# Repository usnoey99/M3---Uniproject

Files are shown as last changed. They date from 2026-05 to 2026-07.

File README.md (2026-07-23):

# M3 - Gruppe 8 RACE TRACK

### Video Demonstration

[RaceTrack Demo Video](https://github.com/user-attachments/assets/90ffaf7d-e557-4ccf-97b7-1830bb99d353)

---

## Manuals & Documentation

Check out the detailed guides and manuals for more information:

* 📖 [User Manual (PDF)](./docs/RacetrackKurzanleitung.pdf)
* 📄 [Developer & Setup Guide](./docs/M3%20-%20Gruppe%208%20-%20Manuell.pdf)

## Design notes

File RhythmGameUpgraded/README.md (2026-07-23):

# 2. Abgabe: PyBadge Rhythm Game

**Abgabe bis: 12. Mai**

## 1) Anpassung des Rhythm Games

- **Aufgabe:** Das Rhythm Game so anpassen, dass nach der Schwierigkeitsauswahl:
  - der Bildschirm schwarz wird, bevor das eigentliche Spiel startet
  - die **Neopixel-LEDs** anstelle des Displays verwendet werden, um Spielsignale anzuzeigen  
    - Falls die Neopixel nicht funktionieren, kann alternativ die **D13-LED** genutzt werden
- **Abgabe:**  
  - `.ino` Datei
  - kurzes Demo-Video (`.mp4`)

**Hinweis:**  
Die LEDs zeigen die aktuelle Spielaufgabe an (z.B. grün für einfache Beats, rot für schwierige Beats).

---

## 2) Storyboards

- **Anforderung:** Mindestens 3 verschiedene Spielideen
- **Fokus:**
  - Nutzerinteraktion
  - Sensoren / Aktuatoren / zusätzliche Hardware
  - Feedback des Systems
- **Abgabe:** PDF-Datei mit den Storyboards

---

## 3) Zwischenpräsentation

- **Aufgabe:** Eine Spielidee auswählen und kurz vorstellen
- **Schwerpunkt:** Interaktion des Spiels
- **Dauer:** Max. 4 Minuten
- **Abgabe:** Präsentationsfolien als PDF

---

## 4) Endabgabe

Alle Materialien müssen am Ende in einer **ZIP-Datei** eingereicht werden:

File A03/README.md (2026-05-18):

# Woche 3

## Übersicht

In der dritten Woche arbeitet die Gruppe selbstständig am Projekt weiter.  
Der Fokus liegt auf:

- praktischer Arbeit im FabLab
- Planung benötigter Bauteile
- Dokumentation des Projektfortschritts

---

# Aufgaben

## 1. Werkstattaufgabe (FabLab)

Erstellt zwei kleinere Objekte, die mit eurem Projekt zusammenhängen.

### Anforderungen

- [x ] Ein Objekt mit dem **3D-Drucker** herstellen

- [x] Ein Objekt mit dem **Laser Cutter** herstellen
- [x] Eigene Designs verwenden (gemacht über pdf und freeCAD)
- [x] Keine fertigen Vorlagen aus dem Internet nutzen

### Ziel

Den gesamten Entwicklungs- und Herstellungsprozess selbst kennenlernen.

### Abgabe

- [x ] Fotos der beiden Objekte
- [x ] Kurze Erklärung zu den Objekten
- [ ] Objekte nächste Woche mitbringen

---

## 2. Bestellliste für Teile

Erstellt eine Liste aller benötigten Bauteile für das Projekt.

### Aufgaben

- [ ] Benötigte Komponenten sammeln
1. **Magnete**(100 Stück, 20x5) 3mmx2mm link: https://www.magnet-shop.net/neodym-magnete/scheibenmagnete/scheibenmagnet-3.0-x-2.0-mm-n35-nickel-haelt-300-g
2. **Neopixel** (noch nicht)
3. **Pogopins/connectors** (50x Stück) müssen 5 pins haben und auch direkt einen connector dazu oder einfach stiftleiste und buchsenleiste??
4. **Microcontroller** (20x stück) evtl noch zubehör wie platinen
5. **Potentiometer** 10k
- [ ] Mengen festlegen
- [ ] Fehlende Teile identifizieren

> Weitere Details folgen in einer separaten Ankündigung.

---

## 3. Fortschrittsbericht

Jede Gruppe erstellt einen kurzen Wochenbericht.

### Der Bericht soll folgende Fragen beantworten

- [ ] Welches Gruppenmitglied hat an welchen Aufgaben gearbeitet?
- [ ] Welchen Fortschritt habt ihr erzielt?
- [ ] Welche Probleme oder Herausforderungen gibt es aktuell?
- [ ] Was sind die nächsten Schritte für die kommende Woche?

### Format

- Maximal 2 DIN-A4-Seiten
- Schriftgröße: 12 pt
- Stichpunkte erlaubt
- Bilder optional
- Bilder zählen nicht zum Seitenlimit

---

# Abgabeformat

## Anforderungen

- [ ] Eine gemeinsame PDF-Datei pro Gruppe
- [ ] Namen aller Gruppenmitglieder
- [ ] Fortschrittsbericht
- [ ] Optional: Bilder des Projektfortschritts
- [ ] Bilder der erstellten Objekte mit kurzer Erklärung

---

# Bewertung

- Aktive Mitarbeit und Anwesenheit im Lab sind wichtig.
- Für diese Abgabe gibt es keine direkten Punkte.
- Der Arbeitsaufwand fließt in die Bewertung des finalen Projekts ein.
- Jedes Gruppenmitglied sollte am Ende alle Teilbereiche erklären können.

---

# Wichtiger Hinweis

Verspätete Abgaben werden negativ bewertet und können im schlimmsten Fall zum Ausschluss aus dem Praktikum führen.

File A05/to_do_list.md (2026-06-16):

# RACETRACK – To-Do Liste A05 | Yeonsu
- [x] **1. PyBadge Racing-Simulator (Prototyp)**
  - [x] Pseudo-3D Rennstrecke mit Basis-Formen (Himmel, Gras, Straße, Auto) implementiert
  - [x] Dynamische Scrolling-Animation der Fahrbahnmarkierungen (BPM fungiert als temporäres Gaspedal)
  - [x] UI-Anzeige für "GEAR" (Oktave) als statischer Platzhalter vorbereitet
  - [x] Temporäre Tastensteuerung (Button A/B für BPM) für die Prototyp-Phase ohne Hardware-Pedal eingerichtet

Der grafische PyBadge-Prototyp ist fertiggestellt: Die einfache Text-UI wurde durch eine Pseudo-3D-Rennstrecke mit flüssiger Scrolling-Animation ersetzt. Da das Hardware-Pedal noch fehlt, steuern die Buttons A/B temporär die BPM (Animationsgeschwindigkeit). Die "GEAR"-Anzeige (Oktave) dient vorerst als statischer Platzhalter, während die UART-Kommunikation fehlerfrei parallel zum neuen Rendering läuft.

- [x] **2. Grafik-Assets (Pixel Art) erstellen**
  - [x] Zeichen-Tool auswählen (z.B. Piskel (piskelapp.com) oder Pixilart (pixilart.com))
  - [x] Sprites entwerfen (Auto, Hintergrund, UI-Elemente)
  - [x] Assets formatgerecht exportieren (max. 160x128 Pixel, .bmp Format / 256 Farben)

- [x] **3. PyBadge Grafik-Integration (CircuitPython)**
  - [x] BMP-Dateien in den CIRCUITPY-Speicher übertragen
  - [x] adafruit_imageload Bibliothek einbinden
  - [x] Bisherige Platzhalter-Formen (TileGrids) durch echte Pixel-Art-Sprites ersetzen

Zudem wurden die bisherigen grafischen Platzhalter durch finale Pixel-Art-Assets (Retro-Hintergrund und Auto) ersetzt. Die erstellten 24-Bit-BMP-Dateien wurden mithilfe der adafruit_imageload-Bibliothek erfolgreich in den CircuitPython-Code eingebunden.

- [x] **4. ESP32 Audio-Synthesizer (Prototyp)**
  - [x] BluetoothA2DPSource Bibliothek integrieren
  - [x] Echtzeit-Klangsynthese (Sinuswelle) im ESP32 programmieren
  - [x] Notenfrequenzen (Circle of Fifths) mit der Audio-Ausgabe verknüpfen
  - [x] Bluetooth-Streaming an externen Lautsprecher einrichten

- [x] **5.BPM & Playback Synchronisation**
  - [x] Notenlänge dynamisch an die aktuelle BPM anpassen (80% des Beat-Intervalls)
  - [x] Audio-Trigger fehlerfrei in die bestehende millis()-Playback-Loop integrieren

Ein Echtzeit-Audiosynthesizer (Sinuswelle) wurde auf dem ESP32 implementiert, der die Frequenzen des Quintenzirkels berechnet und kabellos via Bluetooth A2DP streamt. Tonlänge und Timing passen sich dabei dynamisch der aktuellen BPM an. Damit ist das System nun visuell (PyBadge) und akustisch vollständig synchronisiert. Ein Praxistest mit einem echten Bluetooth-Lautsprecher steht aktuell noch aus und muss zeitnah durchgeführt werden.

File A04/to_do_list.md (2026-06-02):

# RACETRACK – To-Do Liste | Yeonsu

- [x] **1. Entwicklungsumgebung**
  - [x] ESP32 konfigurieren & Blink-Test erfolgreich

- [x] **2. UART-Kommunikation**
  - [x] ESP32 <-> PyBadge verbinden
  - [x] UART testen
  - [x] Befehle senden/empfangen (BPM_UP / BPM_DOWN / START / STOP)

- [x] **3. PyBadge (UI)**
  - [x] UART-Empfang implementieren
  - [x] Buttons -> UART-Befehle senden
  - [x] Display für NOTE / BPM / STATUS
  - [x] Nur UI-Logik (keine Berechnung)

- [x] **4. ESP32 Datenstruktur**
  - [x] BlockType (LEFT / RIGHT / STRAIGHT)
  - [x] Track-Array + playhead

- [x] **5. Eingabesystem (ESP32)**
  - [x] Serielle Eingabe (L / R / S / X)
  - [x] Track-Erstellung testen

Ich habe das technische Fundament erfolgreich fertiggestellt und die UART-Verbindung zwischen ESP32 und PyBadge stabil eingerichtet. Auf dem PyBadge läuft die komplette UI-Logik (CircuitPython) zur Anzeige von BPM, Note und Status sowie zum Senden von Button-Befehlen. Auf dem ESP32 wurde die Track-Datenstruktur implementiert und auf 18 Blöcke optimiert. Das Eingabesystem über den PC-Serienmonitor liest Streckenbefehle (L/R/S/X) fehlerfrei in das Array ein.

---

- [x] **6. Musik-Engine (ESP32)**
  - [x] Circle of Fifths implementieren
  - [x] Notenberechnung basierend auf Track-Richtung

- [x] **7. Playback-Engine (ESP32)**
  - [x] Playhead-Loop implementieren
  - [x] BPM-System im ESP32
  - [x] Timing mit millis()

- [x] **8. Integrationstest**
  - [x] UART-Kommunikation testen (ESP32 <-> PyBadge)
  - [x] BPM beeinflusst Playback
  - [x] Track -> Note -> Loop funktioniert
  - [x] Display zeigt Live-Daten korrekt

Ich habe die Musik- und Playback-Engine des ESP32 erfolgreich implementiert. Die Notenberechnung (Quintenzirkel) passt sich dynamisch der Strecke an, inklusive sicherem Loop-Reset auf die Startnote. Das Playback-Timing wird nun flüssig über millis() gesteuert und durch BPM-Limits (60-240) abgesichert. Der Integrationstest bestätigt eine fehlerfreie Umwandlung der Tracks in Musik sowie eine optimierte Echtzeit-Anzeige auf dem PyBadge (150ms Update-Rate).

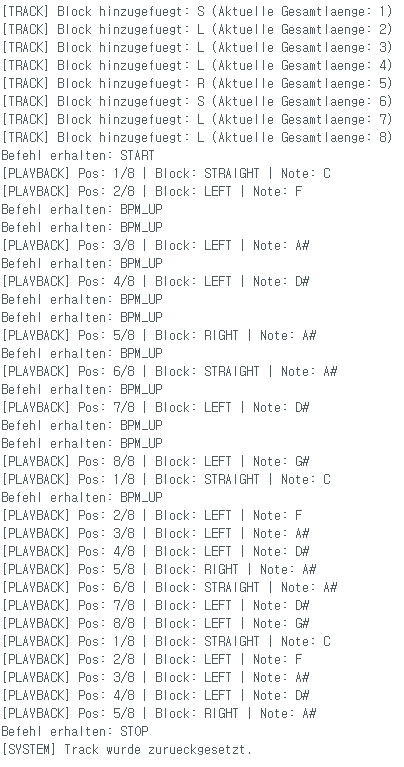
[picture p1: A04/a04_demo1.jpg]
UART Serial Monitor


- [ ] **Optional (Future)**
  - [ ] Pedal-Eingang für BPM (ESP32 übernimmt Steuerung)
  - [ ] Buzzer/Audio-Ausgabe

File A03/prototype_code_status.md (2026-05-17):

# RACETRACK – Prototype

## Beschreibung
Ein einfacher Musik-Step-Sequencer für den Adafruit PyBadge.

## Funktionen
- Circle-of-Fifths Musiksystem (F, C, G, D, A, E, B)
- Schrittbasierte Sequenz (Track-System)
- BPM-Steuerung mit Buttons (A = langsamer, B = schneller)
- Display zeigt Note, BPM und Track-Status
- WAV-Audio wird pro Note abgespielt
- START-Button startet den Sequencer
- SELECT-Button pausiert den Sequencer

## Status
- Sequencer funktioniert
- Display funktioniert
- BPM-Steuerung funktioniert
- WAV-Wiedergabe funktioniert jetzt
- Start/Stop-Steuerung funktioniert

## Aktuelle Einschränkungen
- PyBadge unterstützt nur einen Audio-Stream gleichzeitig
- Keine echte gleichzeitige Wiedergabe mehrerer WAV-Dateien
- Echtzeit-Audio-Mixing ist aktuell nicht möglich

## Nächste Schritte
- Mehrspur-Audio / Audio-Engine untersuchen
- BPM-abhängige Audio-Geschwindigkeit testen
- Hardware-Input mit Microswitches und Pedalen erweitern

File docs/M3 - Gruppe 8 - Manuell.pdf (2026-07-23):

## M3 - Gruppe 8 - A10 Racetrack

Finja Rang
Yeonsu Kang
Merle Hoffmann
1. Idee
Die Grundidee war, angelegt an eine Rennstrecke, ein modulares Spiel zu entwickeln, mit dem man sich einen eigenen Song bauen kann. Je nach Bauteil (Linkskurve, Rechtskurve und Gerade) verändert sich der Ton einen Schritt nach Links oder Rechts im Quintenzirkel. Dadurch entsteht eine kurze Melodie, die immer wieder geloopt wird. Dabei wollen wir erreichen, dass man spielerisch eine einfache Melodie mit Kicks und Snares erstellen kann und dabei gleichzeitig eine haptische Darstellung von Tönen erlebt.
Die physikalischen Streckenblöcke haben dabei jeweils einen ATTiny und bilden eine Chain die vom ESP32 ausgelesen wird. Da jedes Streckenteil einen ATTiny mit einzigartiger Erkennungs-ID besitzt, können wir auch ein Kick- und Snare-Pattern pro Modul durch Widerstände und Jumper codieren. Diese kann man während des Loops auch immer umstecken, da wir durch eine I2C-Verbindung mit dem ESP32 diese immer neu ablesen. Somit entsteht zusätzlich ein weiteres Element in der Musik, welches eher an einen Synthesizer anlehnt. Zusätzlich haben wir noch ein 3D-gedrucktes Pedal mit einem Potentiometer, mit dem man durch Drücken dynamisch den BPM der Musik schneller werden lassen kann.
Auch haben unsere Streckenteile jeweils zwei eingebaute Neopixel, sodass man durch Leuchten in den Farben Rot und Grün erkennen kann, wo man sich im Loop und im Abspielen der Töne gerade befindet (das aktuelle Teil leuchtet Grün, während alle anderen Teile rot leuchten).
Der PyBadge dient hauptsächlich als reine UI. Dabei gibt es das Start- und Stopp-Menü sowie einen Warnbildschirm, falls die Strecke nicht erkannt wird. Zusätzlich kann man auch die Startnote am Anfang über die hoch und runter Knöpfe auswählen. Während der Track läuft, gibt der PyBadge eine visuelle Darstellung eines fahrenden Autos aus mit dem aktuell abspielenden Ton, um die Tonerkennung zu vereinfachen.
2. Benötigte Komponenten
- PyBadge
■ GRD Kabel
■ RX Kabel
■ TX Kabel
■ Batterie oder Stromanschluss ■ 3d-Gehäuse

- ESP32
- Arduino UNO zum Attiny flashen
- 6x Jumperkabel zum ATtiny flashen
- Laptop o.Ä. mit USB Anschluss
- Bluetooth-Lautsprecher
- Potentiometer 25k
- 3.3V Netzgerät
- 2,54 mm Stiftleisten
■ diese haben wir in 100x 2er Pins getrennt und dann oben mit Lötzinn verbunden (als homemade Jumper)
■ dann wurden sie mit Heißkleber in die 3D-gedruckten Pylonen geklebt
Wir haben 13 Streckenteile (3 Links- 3 Rechtskurven und 7 Geraden), die alle die gleichen Komponenten haben. Also ist hier ein Beispiel eines Streckenteils und dieses dann 13 mal:
- 8-Bit-ATtiny 85
- Lochrasterplatine(-n) (Gerade: ca. 10 x 4 cm, Kurven: 2x ca. 5 x 4 cm)
- IC-Sockel
- JST - Buchsengehäuse, 1x6-polig - XH
- JST - Stiftleiste, gerade, 1x6-polig - XH
- 6x JST - Crimpkontakt, Buchse - XH
- 1x 100 µF Elektrolyt-Kondensator
- 2x 10k Widerstände
- 2x 1k Widerstände
- 2x 2k Widerstände (2x1k Widerstände)
- 2x 4k Widerstände (1x 1,8k und 1x 2,2k Widerstände)
- 2x 8k Widerstände (1x 6,8k und 1x 1,2k Widerstände)
- 8x 2,0 x 3,0 mm Scheibenmagnete
- 8x 2er Buchsen
■ + weitere 8x 2er Buchsen
■ diese wurden aufeinander gesteckt und mit Schrumpfschläuchen verbunden damit sie lang genug sind um oben aus dem Gehäuse herausragen zu können
- Schrumpfschläuche
- Gnd Kabel (mehrere Stücke)
- Vcc Kabel (mehrere Stücke)
- 2x Neopixel
- Kabel für SDA (mehrere Stücke)
- Kabel für SCL (mehrere Stücke)
- Kabel für Neo-Data (mehrere Stücke)
- Kabel für Chain-Data (mehrere Stücke)
- Sekundenkleber
- Heißkleber
- 3D-Druck Gehäuse

3. Verkabelung
- UART2 zwischen ESP32 und PyBadge
■ GPIO16=RXD2
■ GPIO17=TXD2
- I2C-Bus (Master ESP32) zu dem ersten angesteckten ATTiny (Adressbereich 0x10–0x1F) durch Stecker
■ GPIO21=SDA
■ GPIO22=SCL
- Chain-Signal zwischen ESP32 und dem ersten angesteckten ATTiny ■ GPIO4=PB4 (Chain-In)
- NeoPixel-Datachain zwischen ESP32 und dem ersten angesteckten ATTiny
■ GPIO5=Neopixel Data-In
- ESP32 und Potentiometer (ADC)
■ GPIO34 = Data von Potentiometer ■ ESP 3.3V an Potentiometer
- ESP GND
■ An PyBadge GND
■ An ATTiny GND
■ An Neopixel GND
■ An Potentiometer GND
- 3.3V Netzgerät
■ Vcc an ATTiny VCC
■ VCC an Neopixel VCC
■ GND and ESP32 GND
- ATTiny Pins:
■ PB0 = I2C SDA (Pin 5)
■ PB1 = Chain-Out (zum nächsten Chain-In) (Pin 6) ■ PB2 = I2C SCL (Pin 7)
■ PB3 = Pin_Kick, ADC3 (Pin 2)
■ PB4 = Chain-In (Pin 3)
■ PB5 = Pin_Snare, ADC0 (Pin 1)
■ GND (Pin 4)
■ VCC (Pin 8)
- Kondensator am Anfang des Streckenteils bei GND und VCC Verbindung
4. Installationsanleitung
- ArduinoIDE herunterladen
- Arduino mit Arduino ISP-Sketch flashen (unter File →Examples → ArduinoISP)

- ATTiny Module flashen:
■ ATTiny mit einem Arduino Uno flashen ■ Steckverbindung

■ 10 µF Kondensator zwischen RESET und GND des Arduino Uno
■ ATTiny Board runterladen (https://github.com/damellis/attiny) ■ Einstellung von Arduino ISP
1. Clock Internal 8MHz
2. Programmer: Arduino als ISP
3. Processor: ATTtiny 85 auswählen
■ Burn Bootloader
■ Upload Code über Upload using Programmer ■ Fuses setzen (lfuse=0xE2, hfuse=0x5F )
1. über Arduino IDE oder
2. Kommandozeile:
avrdude -c stk500v1 -p attiny85 -P /dev/ttyUSB0 -b 19200 -U lfuse:w:0xE2:m -U hfuse:w:0x5F:m
■ Bei jedem Neuen Modul den Adressbereich 0x10–0x1F umändern und die Richtungen 0(Gerade),1(Links),2(Rechts) anpassen
- ESP32 Modul flashen
■ ESP32 Board runterladen (GitHub - espressif/arduino-esp32: Arduino core for the ESP32 family of SoCs · GitHub (https://github.com/espressif/arduino-esp32) )
■ ESP32 Dev Modul auswählen
■ Benötigte Libraries
1. BluetoothA2DPSource
(https://github.com/pschatzmann/ESP32-A2DP)
2. Adafruit_NeoPixel (GitHub - adafruit/Adafruit_NeoPixel: Arduino library for controlling single-wire LED pixels (NeoPixel, WS2812, etc.) · GitHub (https://github.com/adafruit/Adafruit_NeoPixel) )
Arduino Uno | ATTiny85
Pin 10 | Pin1 (PB5)
Pin 11 | Pin 5 (PB0)
Pin 12 | Pin 6 (PB1)
Pin 13 | Pin 7 (PB2)
5V | Pin 8 (VCC)
GND | Pin 4 (GND)

3. Wire (USIWire) (GitHub - puuu/USIWire: USI based TWI/I2C library for Arduino · GitHub (https://github.com/puuu/USIWire) )
4. functionGenerator (GitHub -RobTillaart/FunctionGenerator: Arduino library to generate wave forms (nummeric) for a DAC · GitHub (https://github.com/RobTillaart/FunctionGenerator) ) ■ Bluetooth-Lautsprecher-Name im Code eintragen und koppeln ■ Code auf ESP32 Dev Modul flashen
- Pybadge
■ CircuitPython-Firmware installieren
■ Benötigte Libraries (in den “lib” Ordner auf dem CIRCUITPY-Laufwerk kopieren)
1. adafruit_pybadger
(https://github.com/adafruit/Adafruit_CircuitPython_PyBad ger) (https://github.com/adafruit/Adafruit_CircuitPython_PyBadger)
2. adafruit_imageload
(https://github.com/adafruit/Adafruit_CircuitPython_Image Load) (https://github.com/adafruit/Adafruit_CircuitPython_ImageLoad)
3. adafruit_display_text
(https://github.com/adafruit/Adafruit_CircuitPython_Display_Text) (https://github.com/adafruit/Adafruit_CircuitPython_Display_Text)
■ code.py auf CIRCUITPY-Laufwerk kopieren
■ Bilddateien (bg.bmp, porsche911.bmp, porsche911_2.bmp ) auf CIRCUITPY-Laufwerk kopieren
- Hardware miteinander verbinden (UART, Module in Ketten anschließen)
- Stromversorgungen anschließen
- Einschalten vom PyBadge und starten
- Falls nötig: Serial Monitor prüfen (Baud 115200)
5. Ausführliche Spielanleitung
- Kurz warten bis der Lautsprecher mit dem ESP32 verbunden ist
- Spielende verbinden physische Streckenmodule (L/R/G)

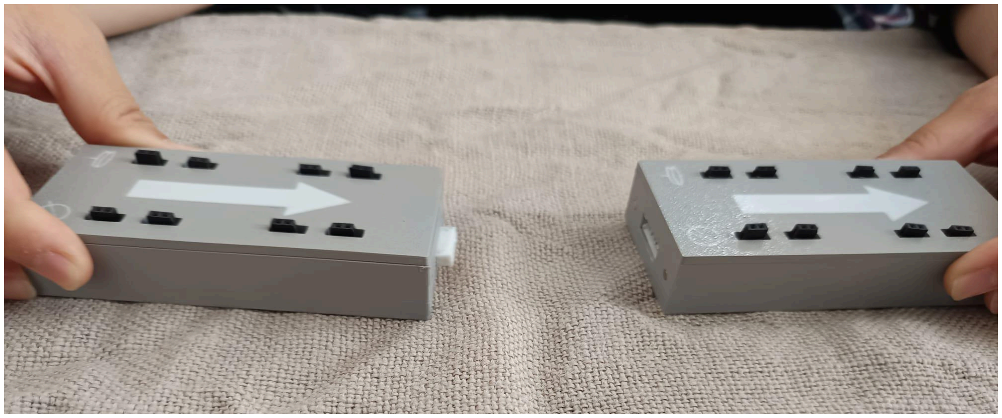
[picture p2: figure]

- Die Spielenden starten PyBadge und wählen darüber die Startnote aus (hoch/runter) und drücken START
- Ablauf PyBagde:

1. Boot-Screen
2. Menü (Startnote)
3. Check_Start ob Module angeschlossen sind
4. Warnbildschirm falls keine Strecke erkannt oder da ist
5. Race-Countdown durch Rote LEDs am PyBadge
6. Spielbildschirm mit Noten/Racing-Animation
- Interaktive Elemente: Kick-/Snare-Pattern kann pro Modul durch das Ein- und Ausstecken der Jumper während des Spiels verändert werden. Die Jumper stehen in Form von Pylonen zur Verfügung.

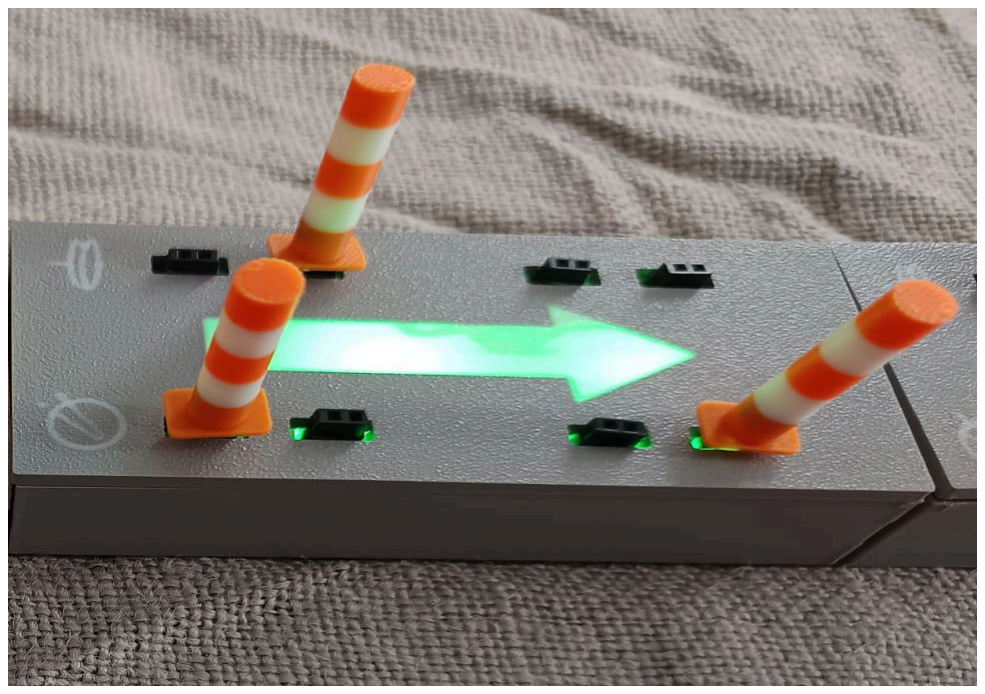
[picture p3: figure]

- Pedal kann von Spielenden runter gedrückt werden (mit Füßen oder Händen) um BPM zu erhöhen
- Um das Spiel zu beenden oder eine neue Strecke zu bauen, drückt man die Taste SELECT.
- Erlaubt/nicht erlaubt:
■ Die maximale Tracklänge ist theoretisch 16 Stück, auch wenn wir nur 13 zur Verfügung haben.
■ BPM-Grenzen liegen bei 70-200
■ Das Pedal ist stabil,sollte aber trotzdem nicht mit voller Kraft runtergedrückt werden.
■ Die Stecker lassen sich manchmal etwas schwer verbinden/trennen, also darf man da auch ruhig mit etwas mehr (nicht voller) Kraft hantieren.
6. Kurzanleitung: separat
7. Bekannte Probleme & Fixes
- Die Steckverbindungen sind etwas fragil. Früher hatten wir nur Pins und Buchsen benutzt, die noch fragiler waren und jetzt benutzen wir JST Stecker, die sind etwas besser. Falls man die Rennstrecke aber nachbauen möchte, würden wir vorschlagen, die jeweiligen Steckverbindungen mit magnetischen Pogo-Pin-Verbindungen nachzubauen. Diese sind etwas kostspieliger aber wären definitiv besser für eine stabile und einfache Verbindung.

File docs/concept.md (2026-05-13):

# Konzeptdokument – „Racetrack“

## 1. Grundidee des Projekts

„Racetrack“ ist ein interaktives System, bei dem physische Rennstrecken-Module zusammengesetzt werden.  
Diese Module bilden gleichzeitig eine musikalische Komposition.

Der Name „Racetrack“ spielt bewusst mit zwei Bedeutungen:
- Rennstrecke (physisch, spielerisch)
- Musik-Track (kompositorisch)

---

## 2. Inspirationsquellen

Das Konzept orientiert sich an klassischen und physischen Spielsystemen wie:
- Carrera-Rennbahnen
- Modelleisenbahnen
- LEGO-Bausystemen

Der Fokus liegt auf physischem Bauen mit direkter Rückkopplung in Musik und Interaktion.

---

## 3. Streckenmodule

Es gibt vier grundlegende Modultypen:

- Linkskurve
- Rechtskurve
- S-Kurve
- Gerade

### Musikalische Bedeutung der Module

Jedes Modul enthält eine musikalische Struktur:
- eigene Melodie oder Soundsequenz
- ca. 8 Noten pro Modul
- konsistenter Klangcharakter pro Modultyp

Durch die Kombination der Module entstehen:
- unterschiedliche Streckenlayouts
- unterschiedliche musikalische Abläufe

---

## 4. Modulerkennung

Jedes Streckenelement wird technisch eindeutig identifiziert.

### Geplanter Ansatz:
- Widerstandswerte pro Modultyp
- gleiche Modultypen teilen sich denselben Widerstand
- Mikrocontroller liest den Widerstand aus und identifiziert das Modul

---

## 5. Interaktion und Spielerlebnis

### Fahrzeugdarstellung
- visuelle Darstellung eines Autos auf einem Display (Pi Badge)
- Animation der Bewegung entlang der Strecke
- visuelle Effekte wie „Wind“ oder Geschwindigkeitseffekte

---

### Beschleunigungssystem
- Nutzung eines Potentiometers als Gaspedal
- optional 3D-gedrucktes Pedal
- Funktion:
  - Druck erhöht Geschwindigkeit
  - Loslassen reduziert Geschwindigkeit

---

### Gangschaltung / Tonhöhen
- physische Buttons oder Hebel als Gangsystem
- mögliche Funktionen:
  - Änderung der Tonhöhe
  - Änderung der Oktave
  - Veränderung musikalischer Parameter

---

## 6. Erweiterte musikalische Ideen

### Loop-System
- Musik kann beim Erreichen des Startpunkts gespeichert und wiederholt werden
- erzeugt musikalische Layer und Harmonien

---

### Akkord-System
- einzelne Module können auch Akkorde repräsentieren
- mögliche 4-Akkord-Struktur basierend auf 4 Modultypen
- Erweiterung der Melodieebene zu harmonischer Struktur

---

## 7. Multiplayer-Konzept

- nur ein aktives Steuergerät (Pi Badge)
- mehrere Personen können gleichzeitig die Strecke bauen
- kollaboratives physisches Gameplay wie bei LEGO-Systemen

---

## 8. Visuelle Effekte (LED-System)

- Einsatz von NeoPixel-LED-Streifen entlang der Strecke
- Darstellung von:
  - Fahrzeugposition
  - Geschwindigkeit
  - Zustandsänderungen

### Fehlerzustand („Red Flag“)
- bei fehlerhafter Strecke:
  - rote LED-Signale
  - visuelle Warnung auf Display

---

## 9. Erweiterungsvision

- realistischeres Fahrgefühl durch alternative Eingabegeräte (z. B. Schaltmechanik)
- dynamische Musikentwicklung während der Fahrt
- stärkere Verbindung zwischen physischem Aufbau und musikalischem Ergebnis

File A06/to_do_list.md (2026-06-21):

# RACETRACK – To-Do Liste A06 | Yeonsu
- [x] **1. Audio-Hardware & Fallback-Plan**
  - [x] ESP32 endgültig mit dem Bluetooth-Lautsprecher verbinden.  
  ~~Fallback-Lösung: Falls die Bluetooth-Verbindung weiterhin fehlschlägt, einen Audio-Verstärker (Amplifier) beschaffen und das Audiosignal kabelgebunden über einen regulären Lautsprecher implementieren.~~
  - [ ] Sound-Optimierung: Feedback zum Sound von den Teammitgliedern einholen und bei Bedarf entsprechende Verbesserungen vornehmen.

- [ ] **2. Grafik- und UI-Überarbeitung**
  - [x] Pixel-Art für das Auto neu zeichnen und verbessern.
  - [x] Benutzeroberfläche (UI) für die gleichzeitige/bessere Anzeige von BMP-Grafiken und Code anpassen.

- [ ] **Optionale Erweiterungen**
  - [ ] Falls Zeit bleibt: Den aktuellen Pixel-Art-Hintergrund durch eine neue Version ersetzen oder weiter optimieren.

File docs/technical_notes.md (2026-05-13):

# Technische Notizen – „Racetrack“

## 1. Systemarchitektur

Das System besteht aus drei Hauptkomponenten:

- physische Streckenmodule
- Mikrocontroller-basierte Steuerung
- visuelle und akustische Ausgabe (Pi Badge + LEDs)

---

## 2. Modulerkennungssystem

### Geplanter Ansatz: Widerstandsbasierte Identifikation

Jedes Modul besitzt:
- einen definierten Widerstandswert
- der beim Einlesen erkannt wird

### Ziel:
- eindeutige Klassifikation jedes Streckenteils
- einfache Hardware-Implementierung ohne komplexe Kommunikation

### Risiko:
- Messungen können ungenau sein
- Kontaktprobleme möglich

---

## 3. Alternative Erkennungsansätze

### Option 1: Mikrocontroller pro Modul
- jedes Modul sendet ID an Hauptsystem
- sehr zuverlässig
- jedoch höhere Kosten und Komplexität

---

### Option 2: QR-Code-Erkennung
- visuelle Identifikation durch Kamera
- einfache Implementierung auf Modulebene

### Nachteil:
- erfordert initiales Scanning aller Module
- weniger geeignet für dynamische Änderungen während des Spiels

---

## 4. LED-System (NeoPixel)

### Einsatz:
- visuelle Darstellung der Fahrzeugposition
- Statusanzeige (z. B. Fehlerzustände)

### Technisches Risiko:
NeoPixel-LEDs blockieren während der Datenübertragung den Mikrocontroller.

#### Auswirkungen:
- keine parallele Verarbeitung möglich
- mögliche Verzögerungen im System
- Einschränkung von Echtzeit-Interaktion

---

## 5. Performance-Überlegungen

### Problem:
- viele LED-Elemente erhöhen Rechenlast
- Echtzeit-Synchronisation von Musik und Licht kritisch

### Empfehlung:
- LED-Updates minimieren oder gruppieren
- klare Trennung zwischen Logik und visueller Ausgabe

---

## 6. Physische Skalierung

### Risiko:
Große Streckensysteme (Carrera-Größe):
- hoher Platzbedarf
- mechanische Instabilität möglich
- erhöhte Komplexität bei Verkabelung

### Empfehlung:
- kleiner Prototyp für erste Entwicklungsphase

---

## 7. Eingabesysteme

### Gaspedal:
- Potentiometer-basierte Eingabe
- optional mechanisches 3D-gedrucktes Pedal

### Gangsystem:
- digitale Buttons im Prototyp
- mögliche spätere mechanische Umsetzung

---

## 8. Audio-System

### Grundprinzip:
- jedes Streckenelement triggert Soundevents
- Sequenzierung basiert auf Fahrzeugbewegung

### Erweiterungsideen:
- Akkordbasierte Audioausgabe
- harmonische Anpassung über Streckenkombinationen
- Loop-basierte Musikstruktur

---

## 9. Systemidee: Sequencer-Logik

Das Fahrzeug kann als „Playhead“ eines Sequencers interpretiert werden.

### Prinzip:
- Bewegung = Trigger für Sound
- Strecke = musikalische Sequenzstruktur

### Vorteil:
- klare Synchronisation von Bewegung und Musik
- einfache Erweiterbarkeit für komplexe Musiksysteme

---

## 10. Risiken und offene Fragen

- Zuverlässigkeit der Modulerkennung
- Synchronisation von Audio und Licht
- Skalierbarkeit des physischen Systems
- Balance zwischen Spiel, Musik und Puzzle

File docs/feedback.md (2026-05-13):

# 📄 Feedback zur Projektidee „Racetrack“

## 1. Projektüberblick

Das Projekt „Racetrack“ kombiniert ein physisches Bau- und Spielsystem mit Musikgenerierung.

Spieler:innen bauen eine Rennstrecke aus modularen Elementen. Diese Strecke bestimmt gleichzeitig eine musikalische Komposition. Dadurch entsteht eine Verbindung zwischen:
- physischem Puzzle-System
- Rennspiel-Mechanik
- musikalischer Interaktion

---

## 2. Feedback zur musikalischen Struktur

### Positive Rückmeldung
Die Grundidee, Musik über physische Interaktion zu erzeugen, wurde als sehr interessant und kreativ bewertet.

---

### Zentrale Kritik: Zufällige musikalische Zuordnung

Die aktuelle Idee, Streckenteile direkt mit Melodien oder Akkorden zu verknüpfen, kann problematisch sein.

#### Problem:
- Akkorde/Melodien werden möglicherweise zu zufällig kombiniert
- musikalische Logik kann verloren gehen
- Ergebnis wirkt eventuell nicht „komponiert“, sondern konstruiert

---

### Vorschlag: Orientierung am Quintenzirkel

Statt feste Akkorde einzelnen Modulen zuzuweisen, sollte das System stärker auf musikalische Bewegung setzen.

#### Idee:
- Rechtskurve = Bewegung im Quintenzirkel in eine Richtung
- Linkskurve = Bewegung in die Gegenrichtung

#### Vorteil:
- harmonisch nachvollziehbare Progressionen
- musikalisch konsistentere Ergebnisse
- höhere Qualität der entstehenden Musik

---

### Tonale Stabilität

Es wurde empfohlen, die musikalische Struktur stärker zu stabilisieren:

- Start und Ende eines musikalischen Durchlaufs sollten tonal zusammenpassen
- Melodien sollten auf einem gemeinsamen Grundton stabilisiert werden

→ sorgt für ein „abgeschlossenes“ musikalisches Gefühl

---

## 3. Strukturelles Kernproblem: Drei gleichzeitige Ziele

Das Projekt verfolgt gleichzeitig drei starke Konzepte:

- Rennspiel
- physisches Puzzle
- Musikinstrument / Musikgenerator

### Problem:
Diese Ziele stehen teilweise in Konkurrenz zueinander.

#### Beispiel:
Spieler:innen optimieren nicht musikalisch, sondern:
- um die Strecke wieder schließen zu können

→ dadurch wird musikalische Kreativität eingeschränkt

---

## 4. Feedback zur musikalischen Richtung

### Eindruck
Die Musik sollte stärker an ein Rennspiel angepasst sein.

### Kritik:
Die bisherige musikalische Idee kann zu ruhig oder abstrakt wirken und passt eventuell nicht ausreichend zum Racing-Kontext.

---

### Vorschläge:
Inspiration aus klassischen Racing-Soundtracks:
- Fast & Furious
- Asphalt-Reihe

### Anforderungen an die Musik:
- hoher Energielevel
- schneller Rhythmus
- klare Dynamik
- „Driving Feeling“

---

## 5. Scope-Problem des Projekts

### Problem:
Das Projekt ist sehr breit angelegt und versucht mehrere komplexe Systeme gleichzeitig umzusetzen:
- Rennspiel
- Puzzle-System
- Musiksystem

### Risiko:
Keines der Systeme wird ausreichend tief oder überzeugend umgesetzt.

---

### Empfehlung:
Ein klarer Fokus sollte definiert werden.

Mögliche Optionen:
- Fokus auf Musiksystem
- Fokus auf Rennspiel
- Fokus auf Puzzle-Mechanik

Die anderen Elemente sollten dann unterstützend wirken.

---

### Alternative Designidee:
- feste Rennstrecke als Grundlage
- Umgebungselemente erzeugen Sound (z. B. Häuser, Bäume, Objekte)

→ reduziert Komplexität und stärkt musikalischen Fokus

---

## 6. Kritik am Loop-System (geschlossene Strecke)

### Problem:
Das aktuelle Konzept basiert auf einem geschlossenen Rundkurs.

#### Konsequenzen:
- starke Einschränkung beim Bauen
- Zwang zur Rückkehr zum Startpunkt
- reduzierte kreative Freiheit

---

### Vorschlag: Sprint-Strecke

Statt eines Rundkurses:
- lineare Strecke (Start → Ziel)

#### Vorteile:
- mehr Freiheit beim Design
- weniger strukturelle Einschränkungen
- einfachere musikalische Logik

---

## 7. Technische Hinweise (NeoPixel)

### Problem:
NeoPixel-LEDs können den Mikrocontroller während des Schreibens blockieren.

#### Risiko:
- Verzögerungen im System
- Einschränkung paralleler Prozesse
- mögliche Probleme bei Echtzeit-Interaktion

---

## 8. Erweiterungsideen für Interaktion

### Track-Switching / Verzweigungen
- alternative Routen im Streckenverlauf
- dynamische Musikwechsel
- A/B-Strukturen möglich

---

### Parallele Tracks
- mehrere gleichzeitig laufende Pfade
- mehrere musikalische Layer

#### Einschränkung:
- Synchronisation bei unterschiedlich langen Pfaden ist schwierig

---

## 9. Physische Skalierung

### Problem:
Große physische Systeme (Carrera-ähnlich) können problematisch sein:
- hoher Platzbedarf
- schwierige Umsetzung
- mögliche Hardwareprobleme (z. B. Wärme, Stabilität)

### Empfehlung:
- kleiner Prototyp für erste Iteration

---

## 10. Erkennung der Module

### Aktueller Ansatz:
- Widerstandswerte zur Identifikation von Modulen

### Herausforderungen:
- technische Zuverlässigkeit unklar
- Fehleranfälligkeit möglich

---

### Alternative Ansätze:
- Mikrocontroller pro Modul (eindeutige Identifikation)
- QR-Code-basierte Erkennung

#### Hinweis:
QR-Code-Systeme erfordern ggf. komplettes Scanning vor Spielbeginn und können die Nutzererfahrung verlangsamen.

---

## 11. Sequencer-Idee (starkes Konzept)

### Grundidee:
Das Fahrzeug fungiert als „Playhead“ eines musikalischen Sequencers.

#### Funktionsprinzip:
- Bewegung auf der Strecke triggert Sounds
- jedes Streckenelement ist ein musikalisches Event

### Vorteil:
- klare Verbindung zwischen Bewegung und Musik
- gut verständliche musikalische Logik
- hohe Erweiterbarkeit

---

## 12. Alternative Systemidee: Stadt- oder Board-System

### Konzept:
Ein festes Spielfeld (z. B. 2×2 Meter) mit vorgegebenem Straßennetz.

### Spieler:innen platzieren:
- Gebäude
- Objekte
- Elemente

### Diese erzeugen:
- Beats
- Sounds
- musikalische Strukturen

### Vorteile:
- stabile Grundstruktur
- bessere Skalierbarkeit
- weniger technische Komplexität

---

## 13. Zusammenfassung der wichtigsten Erkenntnisse

### 1. Fokus des Projekts muss klar definiert werden
Aktuell besteht eine Überladung aus:
- Racing
- Puzzle
- Musik

→ eine klare Priorisierung ist notwendig

---

### 2. Das Loop-Konzept ist kritisch
Die Notwendigkeit, eine geschlossene Strecke zu bauen:
- reduziert kreative Freiheit
- beeinflusst musikalische Entscheidungen negativ

---

### 3. Musiksystem sollte stärker strukturiert sein
Empfehlungen:
- Quintenzirkel
- harmonische Progressionen
- Tonalität und musikalische Stabilität

---

### 4. Racing-Charakter der Musik stärken
- hohe Energie
- schneller Rhythmus
- klare Dynamik
- „Driving Feeling“

---

### 5. Technische Risiken berücksichtigen
- NeoPixel-Blocking
- Skalierungsprobleme
- Track-Erkennung
- physische Komplexität

---

### 6. Sequencer-Ansatz hat hohes Potenzial
Die Idee, das System als musikalischen Sequencer zu interpretieren, wurde als besonders vielversprechend bewertet.

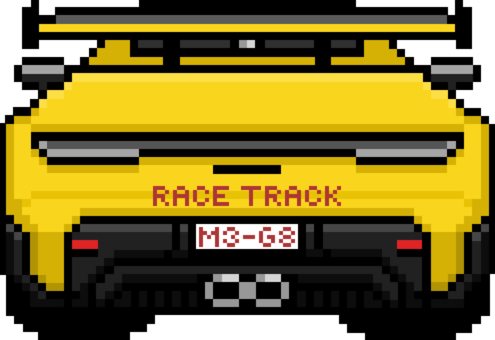
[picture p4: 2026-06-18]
A06/porsche911.bmp

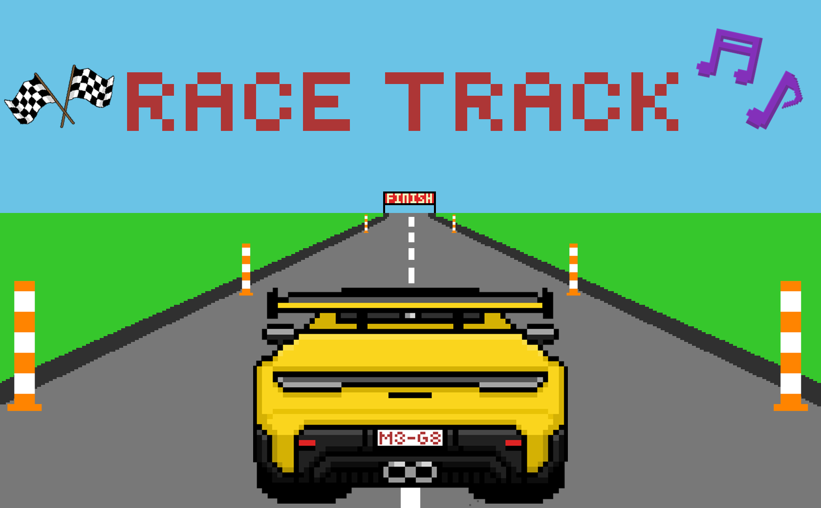
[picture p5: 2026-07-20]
A10_Finale_Abgabe/Thumbnail.png

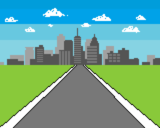
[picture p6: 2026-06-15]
A05/bg.bmp

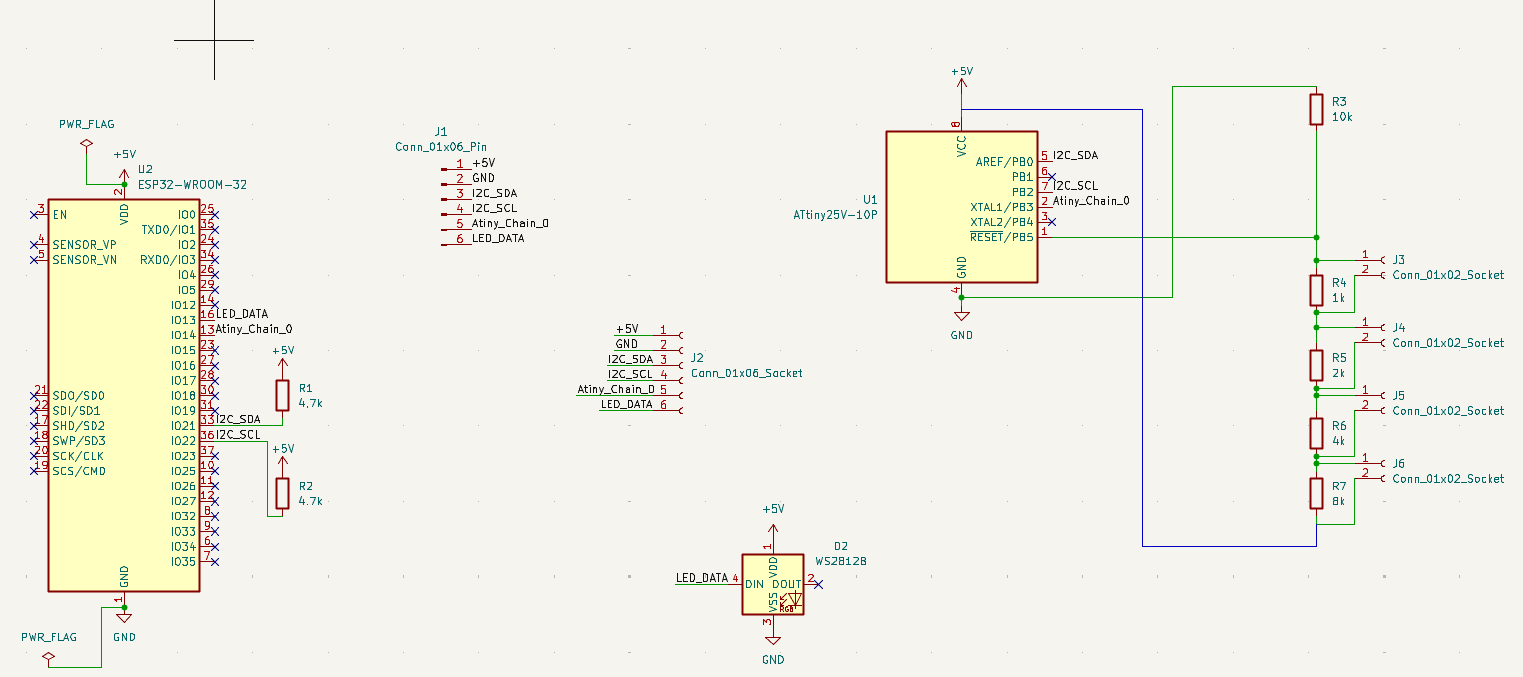
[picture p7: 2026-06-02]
A04/Schaltplan_ESP_MC_NEOPIXEL.png

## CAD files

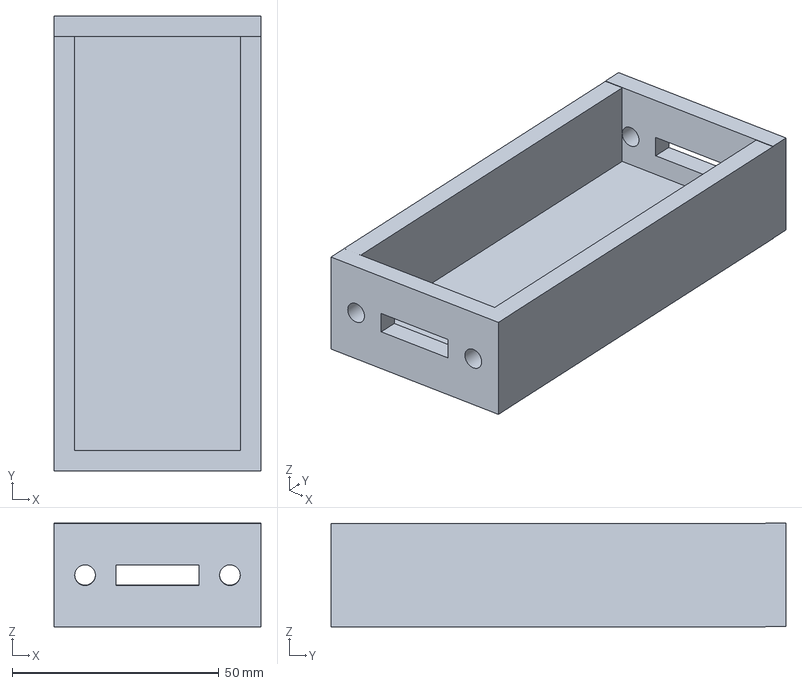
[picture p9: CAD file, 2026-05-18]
A03/Prototyp_1_3mf.3mf
50.0 x 109.9 x 25.1 mm

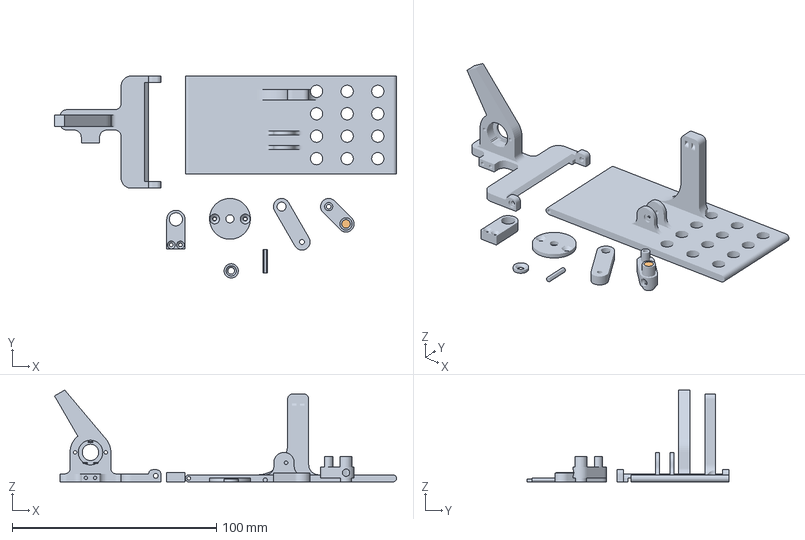
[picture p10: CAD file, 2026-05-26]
A08/pedal.3mf
167.6 x 99.0 x 45.1 mm

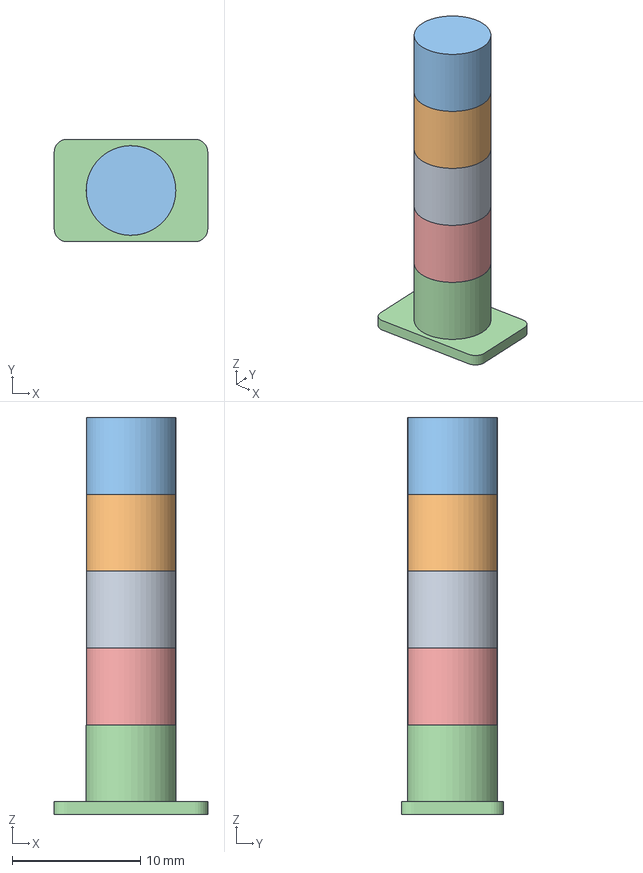
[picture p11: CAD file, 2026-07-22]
A10_Finale_Abgabe/Pylon.3mf
12.0 x 8.00 x 31.0 mm

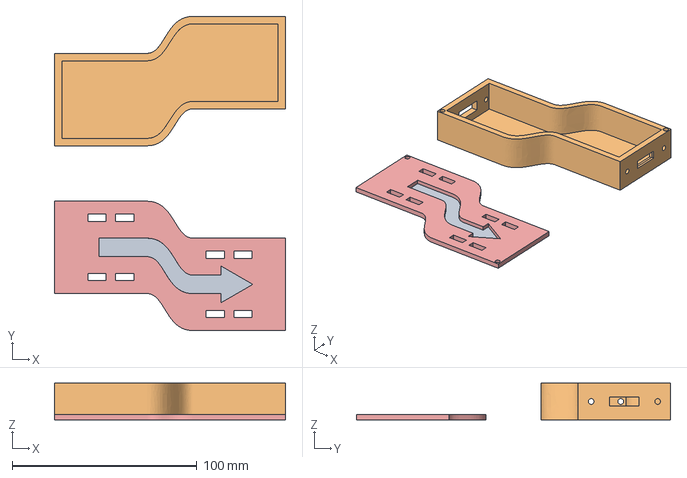
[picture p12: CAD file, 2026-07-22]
A10_Finale_Abgabe/KurveLinks.3mf
125.0 x 170.0 x 20.0 mm

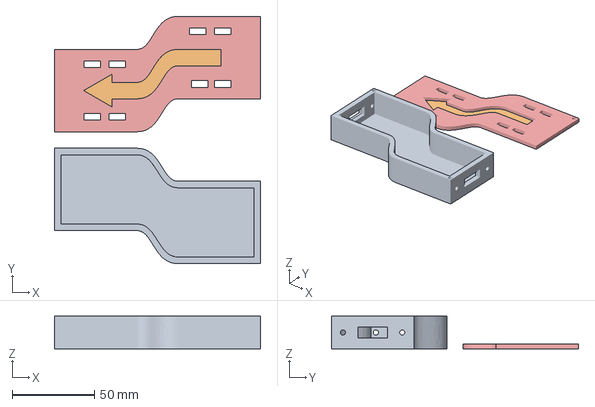
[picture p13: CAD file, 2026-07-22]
A10_Finale_Abgabe/KurveRechts.3mf
125.0 x 150.0 x 20.0 mm

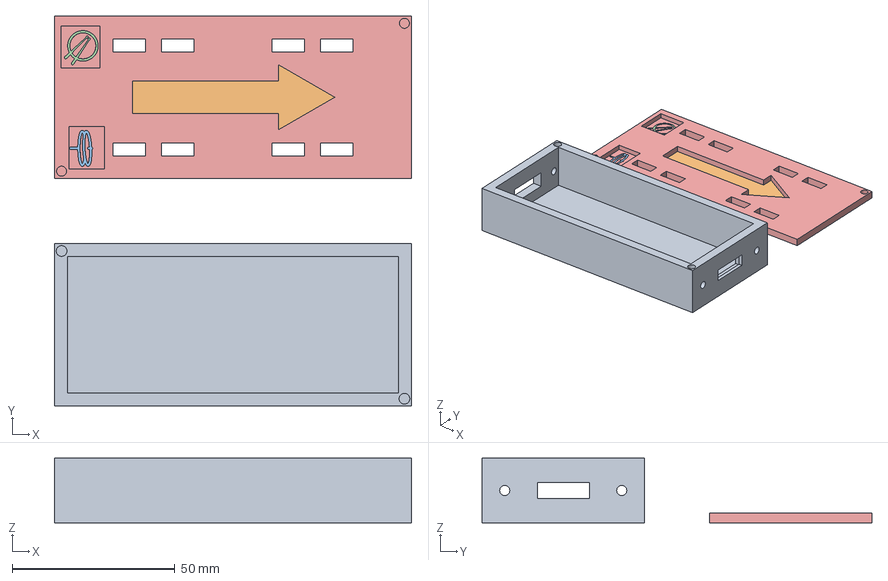
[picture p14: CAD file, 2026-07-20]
A10_Finale_Abgabe/BauteilGerade.3mf
110.0 x 120.0 x 20.0 mm

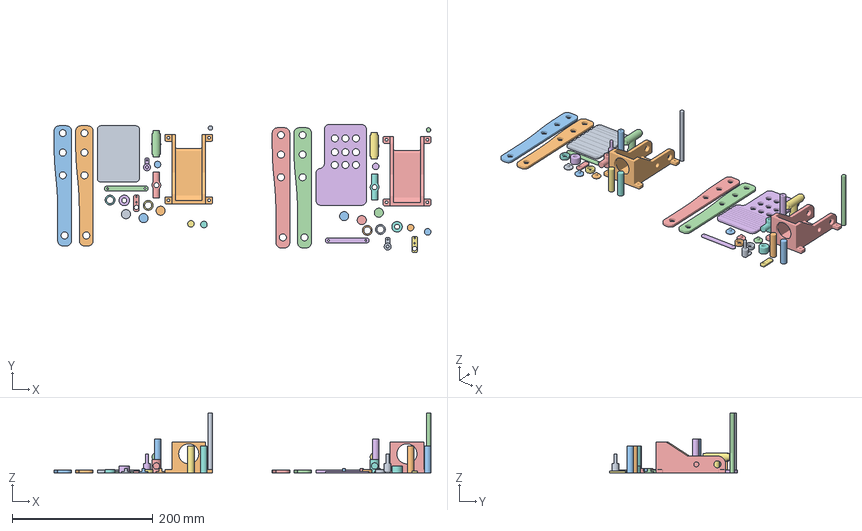
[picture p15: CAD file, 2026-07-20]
A10_Finale_Abgabe/GasPedal.3mf
536.1 x 182.0 x 85.0 mm
spring rod.stl x 2
main body.stl x 2
lower rod.stl x 2
spring connector.stl x 2
slider.stl x 2
potentiometer linkage 2.stl x 2
upper rod.stl x 4
pedal 1.stl
pedal rod.stl x 4
potentiometer linkage 3.stl x 2
potentiometer linkage.stl x 2
spring rod limiter.stl x 2
slider joint.stl x 4
caps.stl x 6
pedal 2.stl

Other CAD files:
A03/Prototyp_1.step

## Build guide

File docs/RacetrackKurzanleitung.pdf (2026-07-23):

Finja Rang
Yeonsu Kang
Merle Hoffmann

## Gruppe 8 - Racetrack - Anleitung

1. Zunächst wird die Grundlage des Songs gebaut: die Melodie! Dafür einfach die gewünschten Teile an das Startteil anstecken, eine Gerade steht hierbei für einen gleichbleibenden Ton, eine Linkskurve für einen Schritt nach links im Quintenzirkel (also fünf Halbtonschritte nach oben) und eine Rechtskurve für einen Schritt nach Rechts im Quintenzirkel (fünf Halbtonschritte nach unten). Dabei achtet man darauf, dass die Teile gut ineinander stecken und möglichst keine Lücken dazwischen sind. Es müssen nicht alle Teile genutzt werden.
2. Nun können auf den Seiten durch das Einstecken von den Pylonen Kicks bzw Snares an den entsprechenden Zählzeiten des Tones eingefügt werden.
3. Auf dem PyBadge wird jetzt mit den hoch und runter Tasten der Startton gewählt und anschließend mit START gestartet.
4. Während nun der aufgebaute Track in einer Schleife abgespielt wird, können die Pylonen weiterhin flexibel ein- und ausgesteckt werden, um die Beats noch zu verändern.
5. Außerdem kann mit dem Pedal die Geschwindigkeit (also die BPM) dynamisch verändert werden.
6. Um den Track zu stoppen drückt man SELECT auf dem PyBadge.

Fehlermanagement:

Strecke(-nteile) werden nicht erkannt/ Strecke leuchtet (teilweise) nicht

Steckverbindungen prüfen und eventuell Teile fester zusammendrücken. Wird gar kein Teil erkannt (also kein Teil leuchtet) Verbindung zum Startteil prüfen.

Wieder ausgesteckte Pylonen werden immer noch erkannt

Ein einzelnes Teil oder gar ganze Strecke noch einmal kurz vom Startteil abstecken und wieder anstecken, ohne neu zu starten.

Stromversorgung ist im Sicherheitsmodus

Einfach hinten am PyBadge mit einem Stab oder dünnen Stift auf den Reset Button drücken.

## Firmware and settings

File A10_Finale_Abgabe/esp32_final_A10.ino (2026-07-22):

// Bluetooth + ATtiny I2C + Chain + NeoPixel + sawtooth


#include <Arduino.h>
#include "BluetoothA2DPSource.h"  
#include <Wire.h>                  
#include <math.h>                  
#include <Adafruit_NeoPixel.h>  
#include "functionGenerator.h"   

// Definition der Pins fuer UART2
#define RXD2 16   
#define TXD2 17   

#define POT_PIN 34  // Potentiometer an GPIO34

// Chain-Kabel 
#define PIN_CHAIN_START 4

// BPM-Grenzen fuer Systemsicherheit
#define MAX_BPM 640  // Maximale BPM-Grenze, um UI-Lag oder Abstuerze zu verhindern, wird nicht voll ausgenutzt, da potentiometer sich nur so 1/3 dreht

#define MIN_BPM 70   // Minimale BPM-Grenze
#define STD_BPM 120  // Standard BPM


// NeoPixel 
// NEO_COUNT = maximale Anzahl LEDs 
#define NEO_PIN   5
#define NEO_COUNT 36
Adafruit_NeoPixel strip(NEO_COUNT, NEO_PIN, NEO_GRB + NEO_KHZ800);

// Farben NeoPIXEL
#define COLOR_STRAIGHT strip.Color( 80,   0,  0)  // Rot
#define COLOR_LEFT     strip.Color( 80,   0,  0)  // Rot
#define COLOR_RIGHT    strip.Color( 80,   0,  0)  // Rot
#define COLOR_PLAYHEAD strip.Color(  0, 255,  0)  // Grün = Auto
#define COLOR_OFF      strip.Color(  0,   0,  0)  // Aus

// Datenstruktur (Track-Array und Playhead)
enum BlockType { STRAIGHT, LEFT, RIGHT, EMPTY };
const int MAX_TRACK = 16; // Maximale Track-Laenge
BlockType track[MAX_TRACK]; // Array zum Speichern der Track-Bloecke
uint8_t   kick_pattern[MAX_TRACK]; 
uint8_t   snare_pattern[MAX_TRACK]; 
uint8_t   module_addresses[MAX_TRACK];
int track_length = 0;   // Aktuelle Laenge des erstellten Tracks
int playhead     = 0;   // Aktuelle Wiedergabeposition (Playhead)
int active_playhead = 0;  // Modul, dessen Takt gerade läuft

// Fail-Safe
int module_miss_count = 0;
#define MAX_MODULE_MISS 10   // Nach 2 Fehlern → Auto-Stop

//  Musik-Engine: Quintenzirkel (Circle of Fifths)
// Lookup-Table fuer die 12 Noten. Einfacher und schneller als mathematische Berechnungen.
const char* circleOfFifths[12] = {
    "C","G","D","A","E","B","F#","C#","G#","D#","A#","F"
};
int start_note_index   = 0;   // 
int current_note_index = start_note_index;

// Frequenzen (Hz) fuer die 12 Noten des Quintenzirkels (Basis: C4 bis B4)
//alle in gleicher Oktave, also nur musikalisch richtig mit hoch und runter
const float note_frequencies[12] = {
    261.63, // C
    392.00, // G
    293.66, // D
    440.00, // A
    329.63, // E
    493.88, // B
    369.99, // F#
    277.18, // C#
    415.30, // G#
    311.13, // D#
    466.16, // A#
    349.23  // F
};

//  Kick und Snare-Frequenz 
#define KICK_FREQUENCY   180.0f
#define SNARE_FREQUENCY  320.0f

#define SAMPLE_RATE      44100.0f
#define MELODY_LEVEL     2300.0f //Lautstärke der Töne

//Lautstärke von Kick und Snare
#define KICK_LEVEL       6500.0f 
#define SNARE_LEVEL      5200.0f

//allgemiene Lautstärke
#define MASTER_LIMIT     30000

// Systemzustand 
struct SystemState {
    int bpm;            
    const char* note;   
    const char* status; 
};
SystemState state;

unsigned long last_send_time = 0;  

// Playback-Engine: Timer-Variable fuer Beats
unsigned long last_beat_time = 0;  

// Bluetooth und Audio-Synthesizer Variablen
BluetoothA2DPSource a2dp_source;

// FunctionGenerator Instanzen (eine pro Ton)
// Amplitude wird spaeter per setAmplitude() gesetzt
// für melody, kick und snare
funcgen melody_osc;
funcgen kick_osc;   
funcgen snare_osc;  

//Melodien-Ton
volatile float current_frequency = 0; // 0 bedeutet Stille
volatile unsigned long sound_duration = 0;
volatile unsigned long sound_start_time = 0;
 

// Kick-Ton
volatile float    kick_current_frequency   = 0;      // 0 bedeutet Stille
volatile uint32_t kick_start_time   = 0;      
volatile uint32_t kick_duration    = 0;   

// Snare-Ton
volatile float snare_current_frequency = 0;
volatile unsigned long snare_start_time = 0;
volatile unsigned long snare_duration = 0;

// Sub-Beat System: 4 Viertel pro Beat
// Bit 0 = Viertel 1, Bit 1 = Viertel 2, Bit 2 = Viertel 3, Bit 3 = Viertel 4
volatile uint32_t subbeat_interval = 0;   
volatile uint32_t last_subbeat_ms  = 0;  
volatile uint8_t  kick_bits_active = 0;   
volatile uint8_t  snare_bits_active = 0; 
volatile uint8_t  current_subbeat  = 0;  

// Callback-Funktion fuer das Bluetooth-Audio-Streaming

static float envelope(float elapsed_ms, float duration_ms, float attack_ms, float release_ms) {
    if (duration_ms <= 0.0f || elapsed_ms < 0.0f || elapsed_ms >= duration_ms) return 0.0f;
    float attack = (attack_ms > 0.0f && elapsed_ms < attack_ms)
        ? elapsed_ms / attack_ms : 1.0f;
    float remaining = duration_ms - elapsed_ms;
    float release = (release_ms > 0.0f && remaining < release_ms)
        ? remaining / release_ms : 1.0f;
    return constrain(attack * release, 0.0f, 1.0f);
}

static int16_t clampSample(float value) {
    if (value > MASTER_LIMIT)  return  MASTER_LIMIT;
    if (value < -MASTER_LIMIT) return -MASTER_LIMIT;
    return (int16_t)value;
}
//  Library gibt Werte zwischen -amplitude und +amplitude zurueck
//sawtooth
// Wir benutzen t = Zeit in Sekunden seit Ton-Start
// Attack: erste 5ms natuerlich einblenden (kein harter Start)
// Decay fuer Note: letzte 20% des Takts ausblenden → klingt harmonischer
// Decay fuer Kick/Snare: linear von 1 auf 0 → perkussiv

int32_t get_audio_data(Frame *channels, int32_t channel_len) {
    // Kontinuierliche Phasen - niemals zurücksetzen!
    static uint32_t melody_samples = 0;
    static uint32_t kick_samples   = 0;
    static uint32_t snare_samples  = 0;
    static float last_melody_frequency = 0.0f;
    static float last_kick_frequency   = 0.0f;
    static float last_snare_frequency  = 0.0f;

    const uint32_t now_ms = millis();

    for (int i = 0; i < channel_len; i++) {
        float sample = 0.0f;

        // Melodie
        if (current_frequency > 0 && now_ms - sound_start_time < sound_duration) {
            if (current_frequency != last_melody_frequency) {
                melody_osc.setFrequency(current_frequency);
                melody_samples = 0;
                last_melody_frequency = current_frequency;
            }
            const float elapsed_ms = (now_ms - sound_start_time) + (i * 1000.0f / SAMPLE_RATE);
            const float env = envelope(elapsed_ms, sound_duration, 18.0f, min(140.0f, sound_duration * 0.22f));
            const float t = melody_samples++ / SAMPLE_RATE;
            sample += melody_osc.sawtooth(t) * MELODY_LEVEL * env;
        } else {
            melody_samples = 0;
            last_melody_frequency = 0.0f;
            if (current_frequency > 0) current_frequency = 0;
        }

        // Kick
        if (kick_current_frequency > 0 && now_ms - kick_start_time < kick_duration) {
            if (kick_current_frequency != last_kick_frequency) {
                kick_osc.setFrequency(kick_current_frequency);
                kick_samples = 0;
                last_kick_frequency = kick_current_frequency;
            }
            const float elapsed_ms = (now_ms - kick_start_time) + (i * 1000.0f / SAMPLE_RATE);
            float env = envelope(elapsed_ms, kick_duration, 3.0f, kick_duration * 0.92f);
            env *= env;                                                                     // quadriert → perkussiver Decay
            const float t = kick_samples++ / SAMPLE_RATE;
            sample += kick_osc.sawtooth(t) * KICK_LEVEL * env;
        } else {
            kick_samples = 0;
            last_kick_frequency = 0.0f;
            if (kick_current_frequency > 0) kick_current_frequency = 0;
        }

        // Snare
        if (snare_current_frequency > 0 && now_ms - snare_start_time < snare_duration) {
            if (snare_current_frequency != last_snare_frequency) {
                snare_osc.setFrequency(snare_current_frequency);
                snare_samples = 0;
                last_snare_frequency = snare_current_frequency;
            }
            const float elapsed_ms = (now_ms - snare_start_time) + (i * 1000.0f / SAMPLE_RATE);
            float env = envelope(elapsed_ms, snare_duration, 2.5f, snare_duration * 0.88f);
            env *= env;  // quadriert → perkussiver Decay
            const float t = snare_samples++ / SAMPLE_RATE;
            sample += snare_osc.sawtooth(t) * SNARE_LEVEL * env;
        } else {
            snare_samples = 0;
            last_snare_frequency = 0.0f;
            if (snare_current_frequency > 0) snare_current_frequency = 0;
        }

        const int16_t output = clampSample(sample);
        channels[i].channel1 = output;
        channels[i].channel2 = output;
    }
    return channel_len;
}

//updateNeoPixelTrack
void updateNeoPixelTrack() {
    for (int i = 0; i < NEO_COUNT; i++) {
        int module = i / 2;                 // Welches Modul gehört diese LED
        
        if (module >= track_length) {
            strip.setPixelColor(i, COLOR_OFF);
            continue;
        }
        if (module == playhead) {
            strip.setPixelColor(i, COLOR_PLAYHEAD);  
        } else {
            switch (track[module]) {
                case LEFT:     strip.setPixelColor(i, COLOR_LEFT);     break;
                case RIGHT:    strip.setPixelColor(i, COLOR_RIGHT);    break;
                case STRAIGHT: strip.setPixelColor(i, COLOR_STRAIGHT); break;
                default:       strip.setPixelColor(i, COLOR_OFF);      break;
            }
        }
    }
    strip.show();
}
// Kick und Snare  live lesen
// Gibt true zurueck wenn Modul erreichbar, false wenn nicht 
bool readKickSnareLive(int position) {
    if (position >= track_length) return true;
    uint8_t addr = module_addresses[position];
    if (addr == 0) return true;

    // 4 Bytes vom ATtiny lesen: direction, kick, snare, chain_active
 Wire.requestFrom(addr, (uint8_t)4);
 delay(20); //kann rein oder auch nicht (manchmal funktioniert es besser ohne)
 
    
    if (Wire.available() >= 4) {
        Wire.read();                           // direction
        kick_pattern[position] = Wire.read();  // kick
        snare_pattern[position] = Wire.read(); // snare
        Wire.read();                           // chain_active
        return true;
    }
    return false;
}

// Schickt RESET-Befehl (0x00) an alle moeglichen Adressen
// Danach sind alle Module bereit fuer einen neuen Scan
void resetAllModules() {
    for (uint8_t addr = 0x10; addr <= 0x1F; addr++) {
        Wire.beginTransmission(addr);
        Wire.write(0x00);  // 0x00 = RESET
        Wire.endTransmission();
    }
    delay(20);  // Kurz warten bis alle Module zurueckgesetzt sind
}


// [NEOPIXEL] Lila Blinken (Verbindungs-Check)

void blinkPurple() {
    Serial.println("[SYSTEM] PyBadge verbunden! LED Bestaetigung (Lila blinken)...");

    for (int b = 0; b < 3; b++) {
        for (int i = 0; i < NEO_COUNT; i++) {
            strip.setPixelColor(i, strip.Color(128, 0, 128)); // alle LEDs lila, unabhängig vom Track
        }
        strip.show();
        delay(250);

        for (int i = 0; i < NEO_COUNT; i++) {
            strip.setPixelColor(i, COLOR_OFF);
        }
        strip.show();
        delay(250);
    }

    updateNeoPixelTrack(); // Danach wieder normale Track-Farben (dort ist die track_length-Abfrage korrekt am Platz)
}



//  scanAndBuildTrack() 

void scanAndBuildTrack() {
    // Alles zuruecksetzen
    track_length       = 0;
    playhead           = 0;
    active_playhead    = 0;
    current_note_index = start_note_index;
    module_miss_count  = 0;
    memset(module_addresses, 0, sizeof(module_addresses));

    Serial.println("[CHAIN] Starte Scan...");
    resetAllModules();

    digitalWrite(PIN_CHAIN_START, HIGH);  // Chain-Signal starten
    delay(200);

    for (int pos = 0; pos < MAX_TRACK; pos++) {
        bool found = false;

        // Alle 16 Adressen abfragen: wer hat chain_active=1?
        for (uint8_t addr = 0x10; addr <= 0x1F; addr++) {
            Wire.beginTransmission(addr);
            if (Wire.endTransmission() != 0) continue;  // Kein Modul da

            Wire.requestFrom(addr, (uint8_t)4);
            if (Wire.available() < 4) continue;

            uint8_t dir          = Wire.read();   // 0=STRAIGHT 1=LEFT 2=RIGHT
            uint8_t kick         = Wire.read();   // Kick-Bitmuster
            uint8_t snare        = Wire.read();   //snare
            uint8_t chain_active = Wire.read();   // 1 = dieses Modul ist dran

            if (chain_active != 1) continue; 

            // Dieses Modul ist Position pos: speichern
            if      (dir == 1) track[track_length] = LEFT;
            else if (dir == 2) track[track_length] = RIGHT;
            else               track[track_length] = STRAIGHT;

            kick_pattern[track_length]     = kick;
            snare_pattern[track_length]    = snare;
            module_addresses[track_length] = addr;  // Adresse merken 

            const char* d = (dir==1)?"LEFT":(dir==2)?"RIGHT":"STRAIGHT";
            Serial.printf("[CHAIN] Pos %d: 0x%02X | %s | kick=%d\n snare=%d\n",
                pos, addr, d, kick, snare);

            track_length++;
            found = true;

            // NEXT senden: leite Chain weiter
            Wire.beginTransmission(addr);
            Wire.write(0x01);
            Wire.endTransmission();
            delay(50);
            break;
        }

        if (!found) {
            //  Track endet hier
            Serial.printf("[CHAIN] Pos %d: kein Modul – Track endet.\n", pos);
            break;
        }
    }

    digitalWrite(PIN_CHAIN_START, LOW);  // Chain-Signal beenden
    Serial.printf("[CHAIN] Fertig: %d Module erkannt.\n", track_length);
    updateNeoPixelTrack();  // LEDs sofort aktualisieren
}

// 
void setup() {
    // Initialisierung der seriellen USB-Verbindung fuer den PC-Monitor
    Serial.begin(115200);
    delay(1000);

    // Initialisierung von Hardware-UART2 fuer die Kommunikation mit dem PyBadge
    Serial2.begin(115200, SERIAL_8N1, RXD2, TXD2);
    Serial.println("ESP32 UART Steuerung Bereit...");


    // I2C als Master starten (SDA=GPIO21, SCL=GPIO22)
    Wire.begin();

    // Chain-Pin konfigurieren
    pinMode(PIN_CHAIN_START, OUTPUT);
    digitalWrite(PIN_CHAIN_START, LOW);

    // NeoPixel initialisieren und alle LEDs ausschalten
    strip.begin();
    strip.setBrightness(60);  // Helligkeit 0-255 (60 = angenehm)
    strip.show();

   // Start-Variablen initialisieren
    state.bpm = STD_BPM;
    state.note = circleOfFifths[current_note_index]; // Startnote "C"
    state.status = "STOPPED";


   // Bluetooth A2DP Source starten (Hier den Namen des Lautsprechers eintragen)
    Serial.println("[SYSTEM] Verbinde mit Bluetooth-Lautsprecher...");
    a2dp_source.start("SoundCore 2", get_audio_data);


    // Kurz warten damit alle Module hochgefahren sind
    delay(1000);

    // Direkt beim Start nach Modulen scannen
    scanAndBuildTrack();
}


void loop() {
    unsigned long current_time = millis();

     // Potentiometer BPM lesen
    int pot_value = analogRead(POT_PIN);
    int new_bpm   = map(pot_value, 0, 4095, MIN_BPM, MAX_BPM);
    
    // Nur aktualisieren wenn Änderung > 4 BPM (verhindert Zittern)
    if (abs(new_bpm - state.bpm) > 4) {
        state.bpm = new_bpm;
        Serial.printf("[POT] BPM: %d\n", state.bpm);
    }

      // Serielle Eingabe
    if (Serial.available()) {
        char c = Serial.read();
        c = toupper(c);  // Kleinbuchstaben in Grossbuchstaben umwandeln

        if (c == 'X') {
            track_length = 0;
             playhead = 0;
             // Note auch auf "C" zuruecksetzen
             active_playhead = 0;
            start_note_index = 0; 
            current_note_index = start_note_index;
            state.bpm = STD_BPM;
            state.note = circleOfFifths[current_note_index];
             // Status auf STOPPED setzen und PyBadge ins Menue schicken
            state.status = "STOPPED";
            module_miss_count = 0;
            Serial2.println("CMD_MENU");  
            updateNeoPixelTrack();

            Serial.println("[SYSTEM] Track wurde zurueckgesetzt. Gehe zum Menue.");
        }
        else if (c == 'I') {
            // Neuer Chain-Scan (Module neu einlesen)
            scanAndBuildTrack();
        }
        // MANUELLER FALLBACK 
        else if ((c == 'L' || c == 'R' || c == 'S') && track_length < MAX_TRACK) {
            if (c == 'L') track[track_length] = LEFT;
            else if (c == 'R') track[track_length] = RIGHT;
            else               track[track_length] = STRAIGHT;
            kick_pattern[track_length]     = 0;  
             snare_pattern[track_length]    = 0;
            module_addresses[track_length] = 0;  
            track_length++;
             Serial.printf("[TRACK] Block hinzugefuegt: %c (Aktuelle Gesamtlaenge: %d)\n", c, track_length);
            updateNeoPixelTrack();
        }
        else if (c == 'P') {
            // START (manuell, auch ohne PyBadge)
            state.status = "RUNNING";
            unsigned long now = millis();
             // Ersten Takt sofort auslösen
            unsigned long beat_interval = 60000UL / state.bpm;
                last_beat_time  = now - beat_interval;
                last_subbeat_ms = now;

                current_subbeat  = 0;
                kick_bits_active = 0;
                snare_bits_active = 0;
                module_miss_count = 0;

                Serial.println("[SYSTEM] START (manuell)");
        }

        else if (c == 'O') {
            // STOP (manuell, auch ohne PyBadge)
            state.status = "STOPPED";
            Serial2.println("CMD_MENU");
            Serial.println("[SYSTEM] STOP (manuell)");
        }
       
        else if (c == 'K') {
            // Kick manuell pro Modul setzen
            // Format: K1=5 → Modul 1 bekommt Kick-Muster 5
            delay(100);
            String input = "";
            while (Serial.available()) {
                input += (char)Serial.read();
                delay(10);
            }
            input.trim();
            
            // Input splitten: "1=5" → Modul 1, Wert 5
            int sep = input.indexOf('=');
            if (sep > 0) {
                int modul = input.substring(0, sep).toInt() - 1; // 0-basiert
                int wert  = input.substring(sep + 1).toInt();
                wert      = constrain(wert, 0, 15);
                
                if (modul >= 0 && modul < track_length) {
                    kick_pattern[modul] = wert;
                    Serial.printf("[KICK] Modul %d → Muster %d (0b%d%d%d%d)\n",
                        modul + 1, wert,
                        (wert>>3)&1, (wert>>2)&1,
                        (wert>>1)&1, wert&1);
                } else {
                    Serial.printf("[KICK] Fehler: Modul %d existiert nicht!\n", modul + 1);
                }
            } else {
                Serial.println("[KICK] Format: K1=5 (Modul=Muster)");
            }
        }
        // Kick manuell pro Modul setzen 
        // nur für testen
        else if (c == 'N') {
            delay(100);
            String input = "";
            while (Serial.available()) {
                input += (char)Serial.read();
                delay(10);
            }
            input.trim();
            int sep = input.indexOf('=');
            if (sep > 0) {
                int modul = input.substring(0, sep).toInt() - 1;
                int wert  = input.substring(sep + 1).toInt();
                wert      = constrain(wert, 0, 15);
                if (modul >= 0 && modul < track_length) {
                    snare_pattern[modul] = wert;
                    Serial.printf("[SNARE] Modul %d → Muster %d (0b%d%d%d%d)\n",
                        modul + 1, wert,
                        (wert>>3)&1, (wert>>2)&1,
                        (wert>>1)&1, wert&1);
                } else {
                    Serial.printf("[SNARE] Fehler: Modul %d existiert nicht!\n", modul + 1);
                }
            } else {
                Serial.println("[SNARE] Format: N1=5 (Modul=Muster)");
            }
        }
    }

    // Playback-Engine (BPM-Timing mit millis)
    // Laeuft nur, wenn der Status "RUNNING" ist und der Track Bloecke enthaelt

    if (String(state.status) == "RUNNING" && track_length > 0) {

        // Berechne Millisekunden pro Schlag (Interval = 60000 / BPM)
        unsigned long beat_interval = 60000 / state.bpm;
        subbeat_interval = beat_interval / 4;  // Ein Viertel = Beat/4
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

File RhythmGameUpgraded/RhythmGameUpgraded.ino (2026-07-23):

/**
 * 
 * Our main file
 * 
 * Änderungen:
 * 1. Nach Schwierigkeitsauswahl im Menü wird das Display schwarz bevor das Spiel startet.
 * 2. NeoPixel LEDs kommunizieren die Beat-Richtung an den Spieler:
 *   - LED 0 = Rechts (directionOffset 0)
 *   - LED 1 = Oben (directionOffset 1)
 *   - LED 2 = Links (directionOffset 2)
 *   - LED 3 = Unten (directionOffset 3)
 *   - LED 4 = Feedback (Grün = gut, Gelb = ok, Rot = schlecht/verpasst)
 * 
 * Farbe der aktiven Richtungs-LED:
 *   - Easy Mode: Grün
 *   - Hard Mode: Rot
 *
 *   Alle anderen Richtungs-LEDs bleiben aus.
 *
 */
 
// We need the Adafruit Arcada Library for our basic functionality
#include <Adafruit_Arcada.h>
#include <Adafruit_NeoPixel.h> // new library
// We can also include our own files in the project
#include "images.h"

// Global variables
Adafruit_Arcada arcada;

// Definition Neopixel
// PyBadge hat 5 NeoPixel LEDs, angeschlossen an Pin 8
#define PIN 8 // Pin für Neopixel-Daten
#define NUMPIXELS 5 // Anzahl der Neopixel-LEDs
Adafruit_NeoPixel pixels(NUMPIXELS, PIN, NEO_GRB + NEO_KHZ800);

// NeoPixel LED-Index Zuweisung für Richtungen
#define LED_RIGHT 0 // directionOffset 0 -> Rechts -> LED 0
#define LED_UP 1 // directionOffset 1 -> Oben -> LED 1
#define LED_LEFT 2 // directionOffset 2 -> Links -> LED 2
#define LED_DOWN 3 // directionOffset 3 -> Unten -> LED 3
#define LED_FEEDBACK 4 // LED 4 -> Feedback (Timing-Qualität)

// Farben für Feedback-LED
#define COLOR_GOOD pixels.Color(0, 255, 0) // Grün = perfektes Timing
#define COLOR_OK pixels.Color(255, 200, 0) // Gelb = akzeptables Timing
#define COLOR_BAD pixels.Color(255, 0, 0) // Rot = schlechtes Timing oder verpasst
#define COLOR_OFF pixels.Color(0, 0, 0) // Aus

// Helligkeit der Richtungs-LED (0–255)
#define BRIGHTNESS_DIRECTION 180


File musicFile;
bool musicIsPlaying = false;
uint32_t bpmTiming = 400;
uint32_t beatTime;

int32_t timingOffset;
bool buttonPressedForLastBeat;
bool buttonReleasedForLastBeat;

int32_t offsetX = 0;
int32_t offsetY = 0;
uint8_t directionOffset = 0;
uint8_t beatDirection = 0;
bool directionUpdate = false;

bool inMenu = true;
bool easyMode = true;
bool menuButtonReleased = true;
bool inBlack = false;



/**
 * The Arduino setup function (called once on startup)
 */
void setup() {
  // initialize arcada library
  if (!arcada.arcadaBegin())
  {
    errorReporter("Fatal error: Arcada library failed.");
  }

  // initialize the file system on the flash (first flashing should be done via CircuitPython)
  if (!arcada.filesysBegin()) { // arcada.filesysBeginMSD() for "USB-Stick" mode
    errorReporter("Fatal error: Filesystem failed.");
  }

  // initialize serial connection
  Serial.begin(9600);
  Serial.println("Booting into game...");
  
  // configure board display and enable frame buffer mode
  arcada.displayBegin();
  arcada.setBacklight(255);
  arcada.createFrameBuffer(ARCADA_TFT_WIDTH, ARCADA_TFT_HEIGHT);

  Serial.println("Initializing display...");

  // we start our loop in the menu
  inMenu = true;

  // NeoPixel initialisieren
  pixels.begin();
  pixels.setBrightness(BRIGHTNESS_DIRECTION);
  pixels.clear();
  pixels.show(); // Alle LEDs auf AUS setzen
  
  Serial.println("Finished booting!");
}


/**
 * The Arduino loop function (called repeatedly)
 */
void loop() {
  // let's just pretend it's a state machine
  if (inMenu) {
    handleMenu();
  } else if (!inMenu && inBlack){
    handleBlack();
  } else {
    handleGameplay();
  }

  // render the frame buffer to the screen
  arcada.blitFrameBuffer(0, 0, true, false);

  // perform standard board functions (cooperative multitasking)
  yield();
}

/**
 * Schwarzer Übergangsbildschirm zwischen Menü und Spiel.
 * Display wird schwarz, dann startet das Spiel direkt.
 */
void handleBlack() {
  // Display schwarz schalten
  GFXcanvas16 *canvas = arcada.getCanvas();
  canvas->fillScreen(ARCADA_BLACK);
  arcada.blitFrameBuffer(0, 0, true, false);

  delay(1500);

  loadMusic();
  randomSeed(millis());
  inBlack = false;
}

/**
 * Handle menu input and rendering
 */
void handleMenu() {
  uint8_t buttonState = arcada.readButtons();
  // Serial.println(buttonState);

  // start pressed: load music and switch to game state
  if (buttonState & ARCADA_BUTTONMASK_START) {
    inBlack = true;
    inMenu = false;
  }

  // select pressed: toggle difficulty
  if (buttonState & ARCADA_BUTTONMASK_SELECT) {
    if (menuButtonReleased) {
      menuButtonReleased = false;
      easyMode = !easyMode;
    }
  } else {
    menuButtonReleased = true;
  }

 // use standard rendering functions without directly updating the screen
  GFXcanvas16 *canvas = arcada.getCanvas();
  canvas->fillScreen(ARCADA_WHITE);
  
  canvas->setTextSize(2);
  canvas->setTextColor(ARCADA_BLUE);
  canvas->setCursor(2, 2);
  canvas->print("Not your");
  canvas->setTextColor(ARCADA_PURPLE);
  canvas->setCursor(18, 18);
  canvas->print("Ordinary");
  canvas->setTextColor(ARCADA_RED);
  canvas->setCursor(34, 34);
  canvas->print("Percussion");
  canvas->setTextColor(ARCADA_ORANGE);
  canvas->setCursor(50, 50);
  canvas->print("Escapade");

  if (easyMode) {
    canvas->drawRGBBitmap(ARCADA_TFT_WIDTH/2 - 32, ARCADA_TFT_HEIGHT - 64, drum_easy, 64, 64);
  } else {
    canvas->drawRGBBitmap(ARCADA_TFT_WIDTH/2 - 32, ARCADA_TFT_HEIGHT - 64, drum_hard, 64, 64);
  }
  
  
}


/**
 * Setzt eine einzelne NeoPixel-LED für die aktuelle Beat-Richtung.
 * 
 * Mapping:
 *  directionOffset 0 -> LED_RIGHT (LED 0)
 *  directionOffset 1 -> LED_UP (LED 1)
 *  directionOffset 2 -> LED_LEFT (LED 2)
 *  directionOffset 3 -> LED_DOWN (LED 3)
 * 
 * Farbe:
 *  Easy Mode -> Blau
 *  Hard Mode -> Lila
 */

void updateDirectionLED(uint8_t direction) {
  // Alle Richtungs-LEDs (0–3) ausschalten
  for (int i = 0; i < 4; i++) {
    pixels.setPixelColor(i, COLOR_OFF);
  }

  // Aktive Richtungs-LED einschalten
  uint32_t dirColor;
  if (easyMode) {
    dirColor = pixels.Color(0, 100, 255); // Blau für Easy
  } else {
    dirColor = pixels.Color(180, 0, 255); // Lila für Hard
  }

  // direction 0-3 entspricht direkt LED-Index 0-3
  if (direction < 4) {
    pixels.setPixelColor(direction, dirColor);
  }

  pixels.show();
}


/**
 * Setzt die Feedback-LED (LED 4) basierend auf dem Timing.
 * 
 * Wird nach jedem Knopfdruck aufgerufen:
 *  |timingOffset| < 50 -> Grün (gut)
 *  |timingOffset| < 90 -> Gelb (ok)
 *  sonst -> Rot (schlecht)
 * 
 * Bei verpasstem Beat -> Rot.
 */
void updateFeedbackLED(bool pressed, int32_t timing) {
  if (!pressed) {
    // Beat verpasst
    pixels.setPixelColor(LED_FEEDBACK, COLOR_BAD);
  } else {
    if (abs(timing) < 50) {
      pixels.setPixelColor(LED_FEEDBACK, COLOR_GOOD);
    } else if (abs(timing) < 90) {
      pixels.setPixelColor(LED_FEEDBACK, COLOR_OK);
    } else {
      pixels.setPixelColor(LED_FEEDBACK, COLOR_BAD);
    }
  }
  pixels.show();
}
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

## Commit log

2026-05-11 Update with Neopixel LED feedback
2026-05-17 prototype_code_status.md update
2026-05-18 Upload New File
    [Prototyp_1.step]
2026-05-26 Modified pedal
    [pedal.3mf]
2026-06-01 Upload esp32_uart_test.ino
2026-06-16 update esp32 mit speacker und audio
2026-06-21 update esp32 ino
2026-07-18 Edit esp32_final_final.ino
2026-07-18 Update file esp32_final_A10.ino
2026-07-19 Edit esp32_final_A10.ino
2026-07-20 Modell für das Gaspedal (von Makerworld)
    [GasPedal.3mf]
2026-07-20 Modell für gerades Streckenteil
    [BauteilGerade.3mf]
2026-07-20 Modell für Rechtskurve
    [KurveRechts.3mf]
2026-07-20 Modell für Linkskurve
    [KurveLinks.3mf]
2026-07-20 Modell für Poller
    [Poller.3mf]
2026-07-20 edit esp32.ino
2026-07-22 Upload Kurve Rechts
    [KurveRechts.3mf]
2026-07-22 Modell Pylon
    [Pylon.3mf]
2026-07-23 change directory
    [BauteilGerade.3mf]
2026-07-23 Move directory
    [GasPedal.3mf]
